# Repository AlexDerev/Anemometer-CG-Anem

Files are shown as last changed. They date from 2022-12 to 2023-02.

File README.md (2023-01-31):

# Портативный анемометр

проект сделан на основе [Official CG-Anem library by ClimateGuard](https://github.com/climateguard/CG-Anem#official-library-for-cg-anem-by-climateguard) и [статьи на Хабре](https://habr.com/ru/post/676348/) 

Цель - попрактиковаться в 3D-моделировании в FreeCAD совместно с дизайном в в KiCAD. И сделать вариант компактного анемометра для параглайдинга.
Исходно набор деталей был взят из статьи:
1. [контроллер WEMOS D1 mini pro](https://aliexpress.ru/item/1005003763905349.html?sku_id=12000027084254255)
2. [USB Модуль зарядки с защитой](https://aliexpress.ru/item/1005003585993852.html?sku_id=12000026386522752)
3. [ADP3338AKC-3.3 регулятор напряжения с низким падением](https://aliexpress.ru/item/4000045988751.html?sku_id=10000000103095880) покупался по линку из статьи. В реальности оказалось подделкой из перепиленного 1117 с падением 1,04 V. В итоге использовался [регулятор MCP1700](https://www.chipdip.ru/product/mcp1700-3302e-to-microchip) в корпусе TO-92.
4. [Экран OLED 1.3"](https://aliexpress.ru/item/1005001621782442.html?sku_id=12000016846377326) вместо 0.96".
5. [Микрик с лапкой на плату](https://roboparts.ru/catalog/kommutatsiya/mikropereklyuchateli_kontsevye_vyklyuchateli/dm3_03p_125v_1a_mikropereklyuchatel/)
6. [Разъем PBS-04 для экрана](https://roboparts.ru/catalog/razemy/shtyrkovye_razyemy/pbs_1x06_razem_na_platu_2_54mm/)
7. [Держатель для 18650 с контактами](https://www.chipdip.ru/product1/8007238837)

## Сравнение с распростаненными у парапланеристов вертушечными анемометрами

### Достоинства
  - Нет вращающихся деталей, нет проблем с подшипниками 
  - Более точный (вероятно). Но нужен прецизионный регулятор напряжения!

### Недостатки

  - Дороже. Типичная вертушка 800 р на Али.
  - Тонкие чувствительные концы. В полевых условиях легко обломать, нужно дополнительно защищать.
  - Отноисительно долгий старт
  - Высокое потребление тока для нагрева горячего конца.
  
  ## Детали реализации
  
  1. Стойки для крепления OLED 11 mm с резьбой M3. Определялось высотой разъема под экран. Впаивать для уменьшения высоты не хотелось.
  2. Диина шурупов для корпуса не менее 20 mm. Исходно сделано под 2.5 mm, но можно рассверлить до 3 mm  в нижней половинке и 2.5 mm в верхней для 3 mm шурупов.
  3. Для кнопки можно использовать пружинку из ручки. Нужно аккуратно рассверлить отверстие в ней до 5 mm.
  4. Для крепления экрана, стоек к плате и сенсора к слайдеру нужны M3 винты с потайной головкой. Длина не более 5 mm.
  5. Исходно печатная плата делалась в Sprint Layout (OLD). В финальном варианте сделана в KiCAD.
  6. 3D модели деталей брались из Интернета, поэтому есть небольшие несостыковки в общей сборке. Дизайн корпуса основывался на реальных деталях. 
  
  ## Планы
  1. Перепроектировать корпус с ипользованием возможности сборки в FreeCAD
  2. Переделать прошивку с выводом графика скорости.
  2. Попробовать уменьшить корпус под использование BL-5C Nokia Li-Ion battery и менее острыми углами.

======================================================================================================
# Handheld Anemometer

Project is based on [Official CG-Anem library by ClimateGuard](https://github.com/climateguard/CG-Anem#official-library-for-cg-anem-by-climateguard) and [habr article](https://habr.com/ru/post/676348/) 

The aim of the project is to practice in 3D-modelling in FreeCAD and electronic design in KiCAD. And to construct the compact anemometer for paraglading.
Initial set of electronic parts was based on the article:
1. [WEMOS D1 mini pro controller](https://aliexpress.ru/item/1005003763905349.html?sku_id=12000027084254255)
2. [USB Li-Ion Charge module](https://aliexpress.ru/item/1005003585993852.html?sku_id=12000026386522752)
3. [ADP3338AKC-3.3 LDO voltage regulator](https://aliexpress.ru/item/4000045988751.html?sku_id=10000000103095880) was taken from the article link. Don't
buy here, it is a fake. Indeed it is remarked 1117 series vith 1,04 V dropout. The [MCP1700 regulator](https://www.chipdip.ru/product/mcp1700-3302e-to-microchip) in TO92 package was used finally.
4. [OLED 1.3" module](https://aliexpress.ru/item/1005001621782442.html?sku_id=12000016846377326) instead of 0.96".
5. [PCB mounted microswitch](https://roboparts.ru/catalog/kommutatsiya/mikropereklyuchateli_kontsevye_vyklyuchateli/dm3_03p_125v_1a_mikropereklyuchatel/)
6. [PBS-04 socket for OLED](https://roboparts.ru/catalog/razemy/shtyrkovye_razyemy/pbs_1x06_razem_na_platu_2_54mm/)
7. [18650 battery holder](https://www.chipdip.ru/product1/8007238837)

## Comparing with conventional rotary handheld anemometers

### Advantages
  - No moving parts - no problems with bearings
  - More accurate (probably). You do need high precision ldo voltage regulator!

### Disadvantages

  - More expensive
  - Sensor ends seem weak and can be broken easily. They need to be additionally protected
  - Relatively long start
  - High current consumption to heat a hotend.
  
  ## Detals
  
  1. OLED screen stands should be 11 mm high and have M3 thread.
  2. The length of case asembling screws should be no less 20 mm. Initially it was supposed to use 2.5 mm screws but you can drill holes up to 3 mm  in bottom part and 2.5 mm in top part to use 3 mm screws.
  3. You can use a spring for button from a pen. In this case you need to drill carefully a hole in the button up to 5 mm diam.
  4. You need to use the short M3 countersunk head screws to attach screen stands to PCB and a sensor plate to a slider. Length should be no more then 5 mm.
  5. PCB layout is designed in Sprint Layout software (OLD). PCB was redesigned in KiCAD.
  6. 3D models of electronic parts were taken from Internet and they seem slightly differ from real parts. The case design is based on the real ones. 
  
  ## TO-DO List
  1. Redesign the case in FreeCAD to use the assembling features
  2. Try to make a new compact case for BL-5C Nokia Li-Ion battery and without sharp corners.

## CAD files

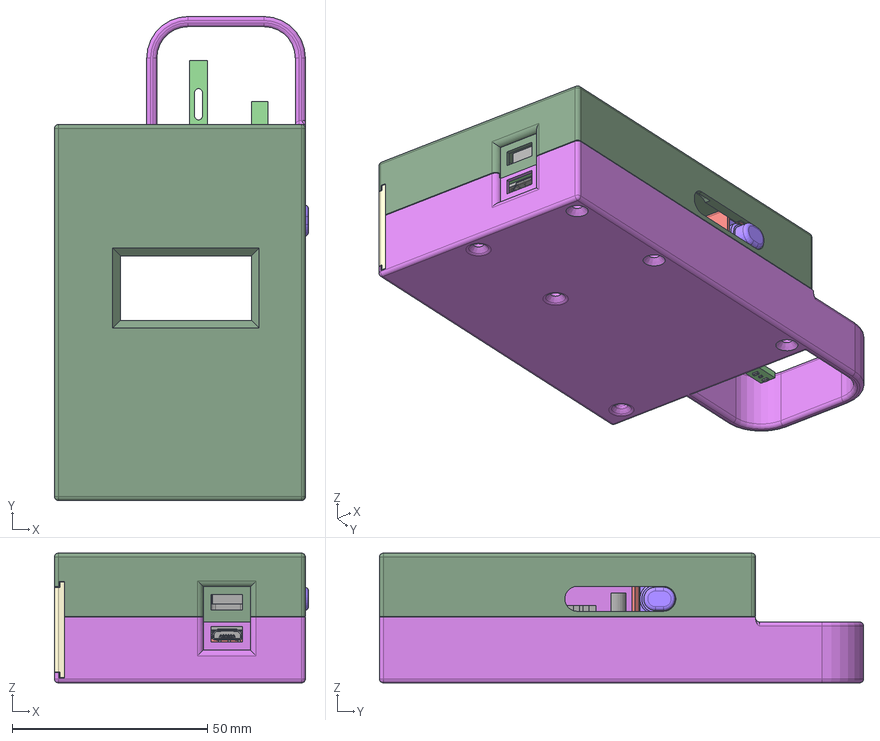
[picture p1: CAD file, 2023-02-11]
Case/Anemometer case.FCStd
65.0 x 123.8 x 33.2 mm
Case bottom
Sensor slider
Button
Case top
BattCover
Battery case
uag PCB
PCB
wire
Screen
Pins
M3x11xx5-Spacer
M3x11xx5-Spacer001
M3x5-Screw
M3x5-Screw010
M3x5-Screw011
M3x5-Screw012
M3x5-Screw029
M3x5-Screw030
M3-Nut
M3-Nut001

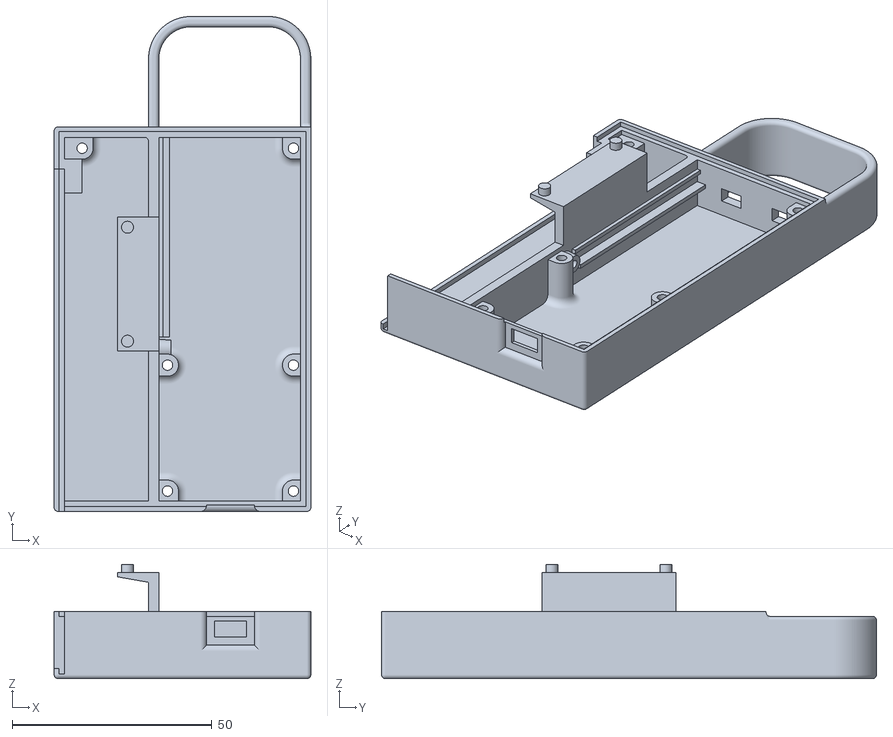
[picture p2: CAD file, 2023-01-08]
Case/Case bottom.stl
64.2 x 123.8 x 28.6

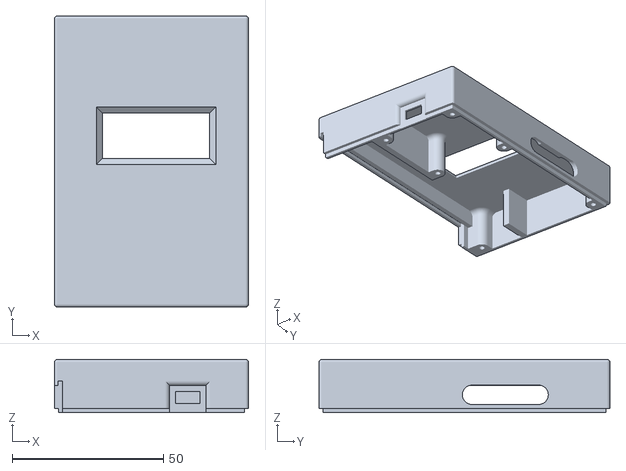
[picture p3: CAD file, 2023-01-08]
Case/Case top.stl
64.2 x 96.2 x 17.6

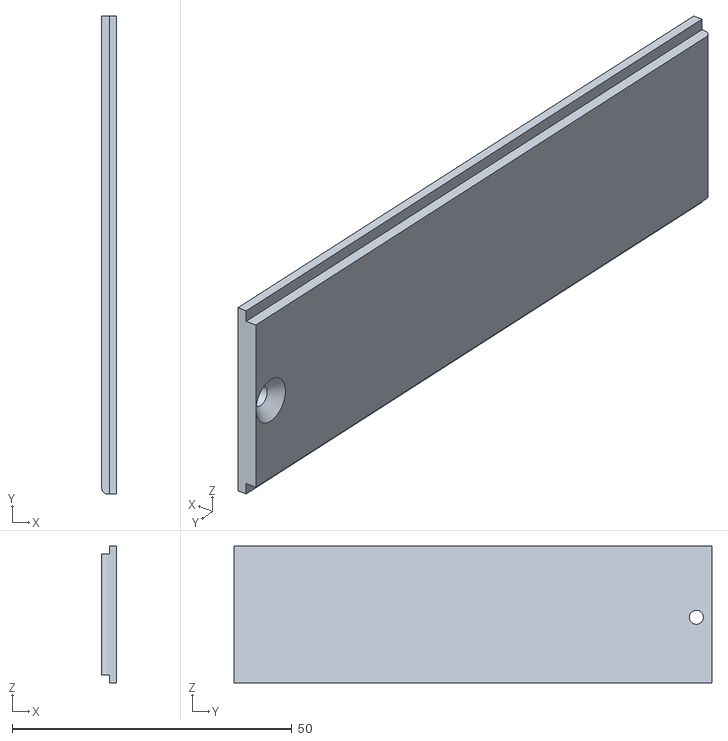
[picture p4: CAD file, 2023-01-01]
Case/Battery cover.stl
2.60 x 85.4 x 24.4

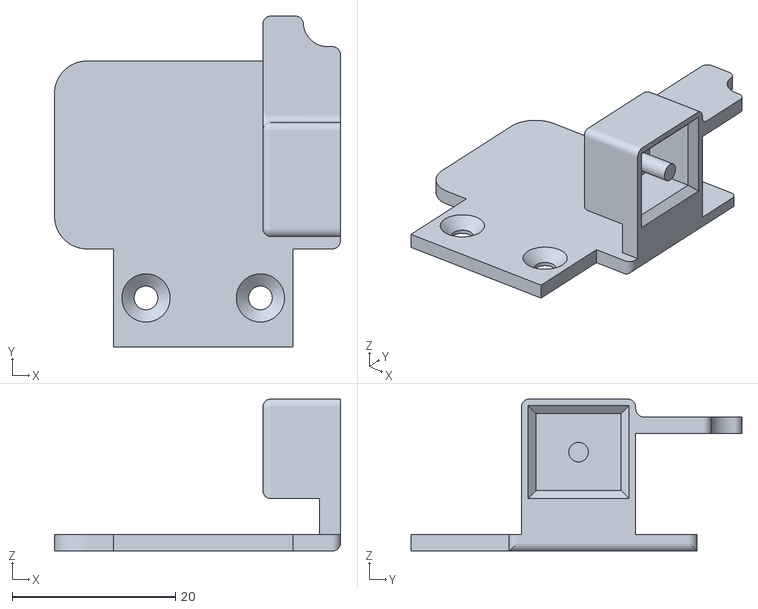
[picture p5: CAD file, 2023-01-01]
Case/Sensor Slider.stl
35.0 x 40.5 x 18.6

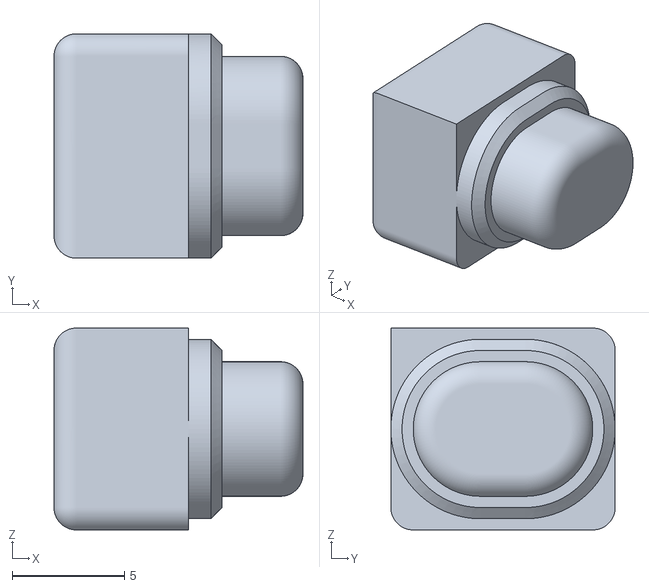
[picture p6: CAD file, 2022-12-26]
Case/Button.stl
11.1 x 10.0 x 9.00

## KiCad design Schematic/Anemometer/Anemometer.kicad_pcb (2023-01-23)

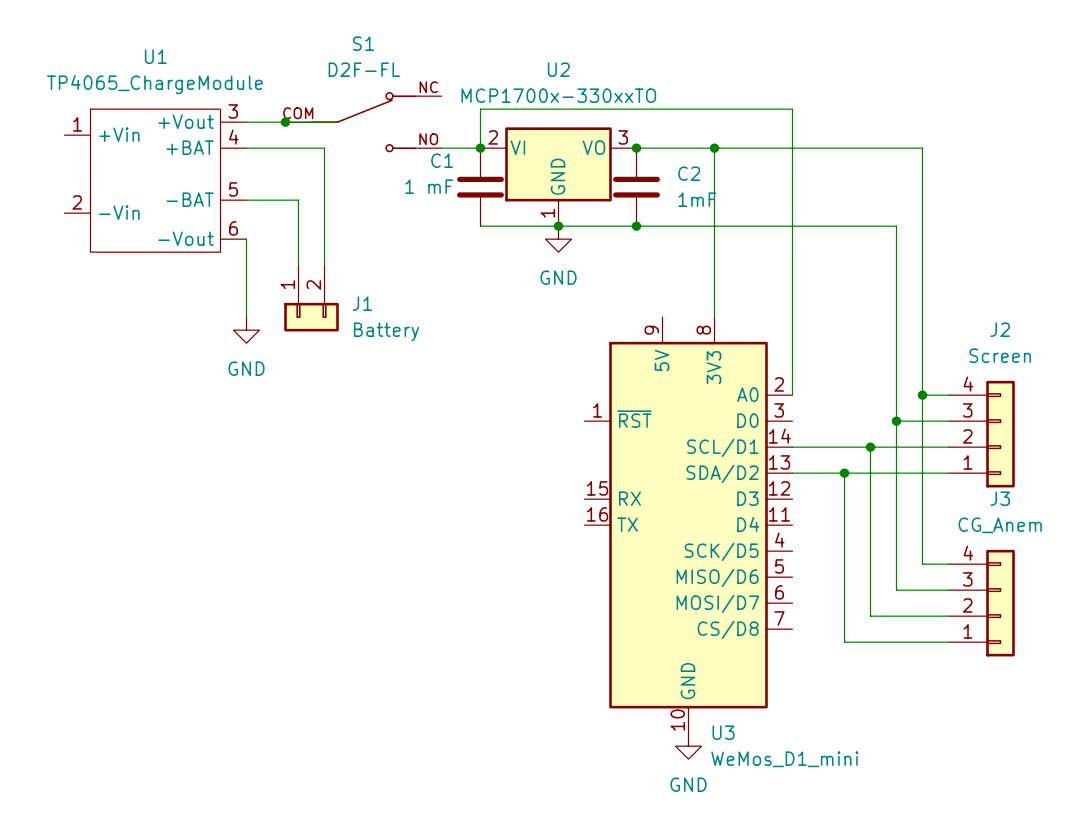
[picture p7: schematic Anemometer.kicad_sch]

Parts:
C1: 1 mF; C_1206_3216Metric
C2: 1mF; C_1206_3216Metric
J1: Battery; JST_EH_S2B-EH_1x02_P2.50mm_Horizontal
J2: Screen; PinSocket_1x04_P2.54mm_Vertical
J3: CG_Anem; JST_EH_S4B-EH_1x04_P2.50mm_Horizontal
S1: D2F-FL; SW_D2F-FL; PARTREV N/A
U1: TP4065_ChargeModule
U2: MCP1700x-330xxTO; TO-92_Inline
U3: WeMos_D1_mini; WEMOS_D1_mini_light

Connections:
GND: C1.2, C2.2, J2.3, J3.3, U1.6 (-Vout), U2.1 (GND), U3.10 (GND)
unnamed: C1.1, S1.NO, U2.2 (VI), U3.2 (A0)
unnamed: C2.1, J2.4, J3.4, U2.3 (VO), U3.8 (3V3)
unnamed: J2.1, J3.1, U3.13 (SDA/D2)
unnamed: J2.2, J3.2, U3.14 (SCL/D1)
unnamed: S1.COM, U1.3 (+Vout)
unnamed: J1.2, U1.4 (+BAT)
unnamed: J1.1, U1.5 (-BAT)

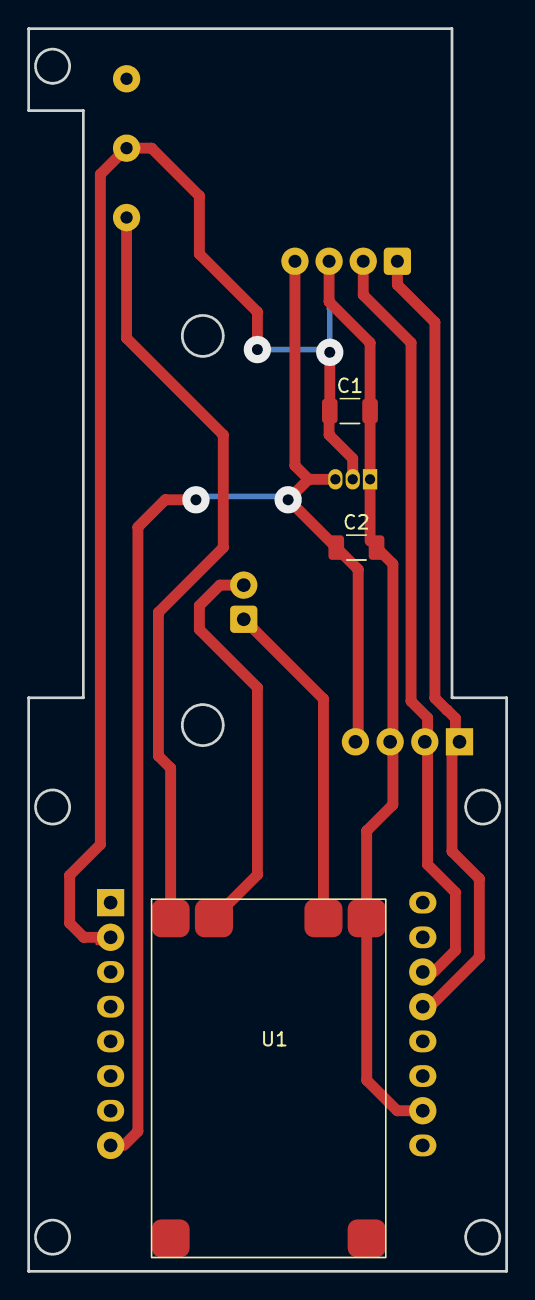
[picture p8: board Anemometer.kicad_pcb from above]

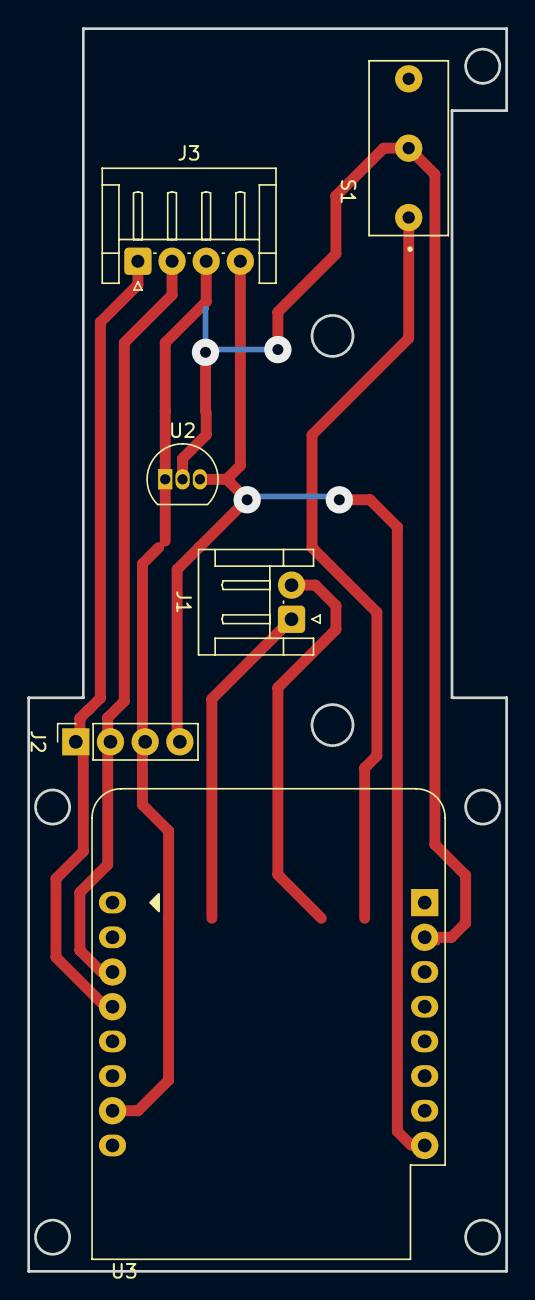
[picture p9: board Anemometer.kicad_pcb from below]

Board: 2 copper layers, 35.0 x 91.0 mm, 9 parts (6 on the bottom side), 8 nets.

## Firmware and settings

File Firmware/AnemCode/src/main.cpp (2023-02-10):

// Инициализируем библиотеки
#include "cgAnem.h"
#include <Wire.h>
#include <GyverOLED.h>

#include "FlowPlot.h"
#include "FlowPlot.cpp"

#define ADC_pin A0 // задаём значение пина АЦП
#define PLOT_LEFT   67  // левая граница графика
#define PLOT_TOP    10  // левая граница графика
#define PLOT_HEIGHT 50  // высота графика
#define PLOT_COUNTS 60  //количество отсчетов на графике

GyverOLED<SSH1106_128x64> oled; // Инициализируем OLED-экран
CG_Anem cgAnem(ANEM_I2C_ADDR); // Инициализируем CG_Anem
FlowPlot<PLOT_COUNTS> flowPlot;

uint16_t ADC; // Переменная для значений АЦП
uint32_t timer_cnt; // Таймер для измерений анемометра
uint32_t timer_bat; // Таймер для измерения заряда батареи
const uint8_t *p;
float flow;

void setup() {
  char buf[10];
  int8_t timeToWait = 10;
  int8_t warmRectWidth = 60;
  pinMode(ADC_pin, OUTPUT); // Инициализируем АЦП как получатель данных
  oled.init(); // Инициализируем OLED в коде
  oled.flipV(1); // Я перевернул экран для удобства
  oled.flipH(1); // Для нормального отображения после переворота нужно инвертировать текст по горизонтали
  oled.clear();

  oled.setCursor(0, 0);
  sprintf(buf, "HW: %.1f", cgAnem.getFirmwareVersion()); 
  oled.print(buf);

  oled.setCursor(0, 5);
  oled.print("Warming");

  oled.setScale(2); // Устанавливаем размер шрифта
  oled.setCursor(20, 2);
  oled.print("CG_Anem");

  oled.rect(45, 40, 45+warmRectWidth, 48, OLED_STROKE);
  oled.update();

  cgAnem.init();
  for (int i = 0; i <= timeToWait; i++) { // Функция таймера служит для предварительного нагрева анемометра перед использованием
    oled.rect(45, 40, 45+warmRectWidth/timeToWait*i, 48, OLED_FILL);
    oled.update();
    delay(1000);
    oled.update();
  }
  delay(1000);
  oled.clear();
  oled.update();
  flowPlot.init(PLOT_HEIGHT);
  p = flowPlot.getPoints();
}

void loop() {
  char buf[50];
  oled.setScale(1);
  if (millis() - timer_cnt > 1000) { // Снимаем показания с анемометра и выводим их на экран
    timer_cnt = millis();
    // Проверяем, обновляются ли данные с анемометра. Если да - выводим их, если нет - предупреждаем об ошибке
    //
    // if (cgAnem.data_update()) {
    cgAnem.data_update();
      flow = cgAnem.getAirflowRate();
      flowPlot.pushValue(flow);
      sprintf(buf, "T:%.1fC ", cgAnem.getTemperature()); // Собираем строку с показаниями температуры
      oled.setCursor(0, 0);
      oled.print(buf);
      
      // отрисовка графика
      oled.rect(PLOT_LEFT, PLOT_TOP, PLOT_LEFT + PLOT_COUNTS, PLOT_TOP + PLOT_HEIGHT, OLED_CLEAR); 
      oled.rect(PLOT_LEFT, PLOT_TOP, PLOT_LEFT + PLOT_COUNTS, PLOT_TOP + PLOT_HEIGHT, OLED_STROKE);
      for (uint8_t i = 0; i < PLOT_COUNTS; i++) {
        oled.dot(PLOT_LEFT + i, PLOT_TOP + p[i], OLED_FILL);
      }
  
      sprintf(buf, "%.1f", flowPlot.getMaxRange()); // Собираем строку со значением для верхней границы
      oled.setCursorXY(PLOT_LEFT - 20, PLOT_TOP);
      oled.print(buf);

      sprintf(buf, "%.1f", flowPlot.getMinRange()); // Собираем строку со значением для нижней границы
      oled.setCursorXY(PLOT_LEFT - 20, PLOT_TOP + PLOT_HEIGHT - 8);
      oled.print(buf);

      sprintf(buf, "M:%.1fm/s", flowPlot.getMeanFlow()); // Собираем строку со средним потоком
      oled.setCursor(55, 0);
      oled.print(buf);

      oled.setCursor(45, 4);
      oled.println("m/s");

      sprintf(buf, "%.1f", flow); // Собираем строку с показаниями скорости потока
      oled.setCursor(0, 3);
      oled.setScale(2);
      oled.print(buf);
    /*
    }
    else {
      oled.setCursor(35, 0);
      oled.print("*");
    }
    */
  }

  if (millis() - timer_bat > 10000) { //
    timer_bat = millis();
    ADC = analogRead(ADC_pin); // Считываем показание с АЦП
    oled.rect(112, 0, 124, 3, OLED_STROKE); // Рисуем иконку батарейки
    oled.rect(125, 1, 127, 2, OLED_FILL);
    if (ADC >= 970) {
      oled.rect(112, 0, 124, 3, OLED_FILL);
    }
    if (ADC < 970 && ADC >= 870) {
      oled.rect(112, 0, 121, 3, OLED_FILL);
    }
    if (ADC < 870 && ADC >= 770) {
      oled.rect(112, 0, 118, 3, OLED_FILL);
    }
    if (ADC < 770 && ADC >= 670) {
      oled.rect(112, 0, 115, 3, OLED_FILL);
    }
  }

  oled.update();
}

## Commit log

2022-12-26 3D Case model added
    [Anemometer case.FCStd, Battery cover.stl, Button.stl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]
2022-12-27 Fix cover slot on case top part
    [Anemometer case.FCStd, Case top.stl]
2022-12-27 Top cover and slider fixed
    [Anemometer case.FCStd]
2022-12-30 PCB Created
    Designed in Sprint Layout
2022-12-30 Fix errors after test assembling
    Не были учтены торчащие выводы из материнки. Не было места для головок винтов крепления сенсора к слайдеру. Слайдер и сенсор опущены на 1.5 мм. Отверстия крепления в слайдере уменьшены для нарезки резьбы М3, винты М3х5 будут вкручиваться снизу.
    [Anemometer case.FCStd, Case bottom.stl, Sensor Slider.stl]
2023-01-01 Залит скетч из примера
2023-01-01 Fixes after full assembling
    Отверстия в слайдере увеличены обратно, сделаны под потайную головку. На PCB аналогично увеличены отверстия под стойки для потайных М3. Увеличены размеры отверстий под USB, коннектор не входил до конца. Уменьшены размеры окна под дисплей.
    [Anemometer case.FCStd, Battery cover.stl, Case bottom.stl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]
2023-01-01 Update Anemometer case.FCStd
    [Anemometer case.FCStd]
2023-01-03 PCB Update
    Убрано соединение SLEEP сенсора на землю.
    Добавлена PCB для регулятора LD39050. Есть в продаже по разумной цене. Но монтировать тяжелее.
2023-01-05 Create Main PCB(MCP1700 reg).lay6
    Сделана разводка под регулятор MCP1770 в корпусе TO-92. У него ток всего 250mA, немного хуже точность регулирования, но значительно дешевле.
2023-01-05 Update Main PCB.lay6
    Небольшая ошибка в разводке земли. Некритично, но все-таки
2023-01-06 Schematic and PCB in KiCAD
    Схема и плата для регулятора MCP1700 в корпусе ТО-92
    [Anemometer.kicad_pcb, Anemometer.kicad_sch]
2023-01-08 Case and PCB Fixes
    Правки сборки после перевода на стаб MCP1700.
    Вместо полных вырезов для USB сделаны выемки. Их достаточно.
    Передвинут разъем к сенсору на PCB, иначе провода загибаются прям впритирку к корпусу.
    [Anemometer case.FCStd, Anemometer.kicad_pcb, Case bottom.stl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]
2023-01-08 Create cg_amen_1v1.step
    Добавлен 3D модель сенсора
2023-01-11 Added PCB 3D model
    [Anemometer case.FCStd, Anemometer.kicad_pcb, Anemometer.kicad_sch]
2023-01-12 Detaled 3D models added
    Добавлены нормальные 3D модели базовой платы, экрана, стойки и винты крепления.
    [Anemometer case.FCStd]
2023-01-23 PCB Updated
    Перемычка мешала слайдеру
    [Anemometer.kicad_pcb]
2023-01-24 Sprint lauout PCB directory renamed
2023-01-24 Update main.cpp
    Начата переделка прошивки. Обновлен стартовый экран добавлен прогресс ожидания, убраны лишние данные с рабочего экрана.
2023-01-31 Flow Plot added (Draft)
    Добавлен класс для расчета точек графика скорости, чтобы можно было выводить на экран
2023-02-01 Update Anemometer case.FCStd
    Слегка поправлено окошко для экрана, немного заходило на нижнюю часть
    [Anemometer case.FCStd]
2023-02-01 Comments added
    Расширены комментарии
2023-02-09 Rearranged main screen
    Облагорожен основной экран, выведены верхние и нижние границы, переставлены значения и пр.
2023-02-10 Fine tuning
    [Anemometer case.FCStd]
2023-02-11 Updated display window position modified: Case/Anemometer case.FCStd
    [Anemometer case.FCStd]
